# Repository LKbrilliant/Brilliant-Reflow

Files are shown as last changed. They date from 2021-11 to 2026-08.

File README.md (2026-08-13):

# Brilliant-Reflow
A complete DIY solution for converting a consumer oven into a temperature controlled reflow oven for PCB soldering.

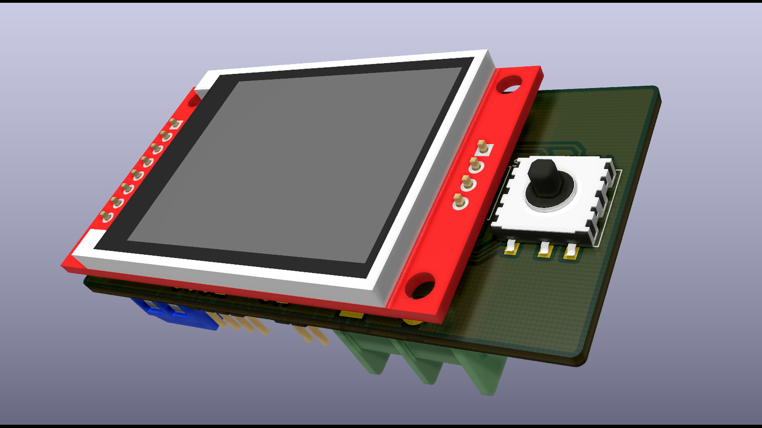
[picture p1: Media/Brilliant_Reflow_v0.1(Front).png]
PCB Front

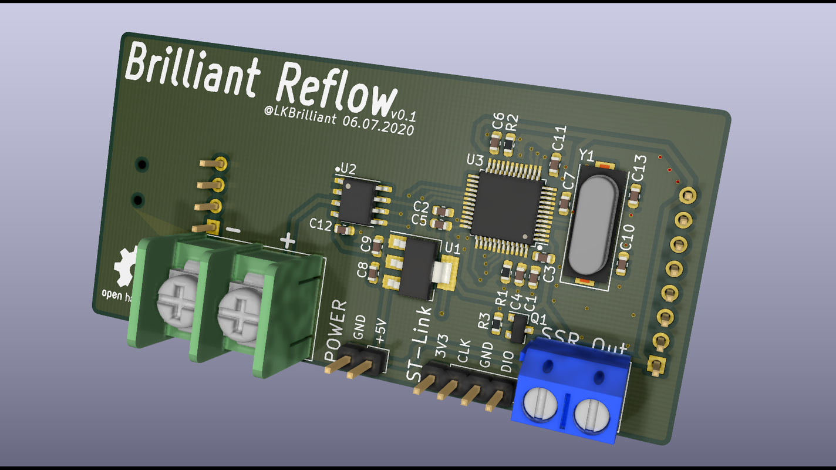
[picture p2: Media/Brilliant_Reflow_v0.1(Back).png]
PCB Back

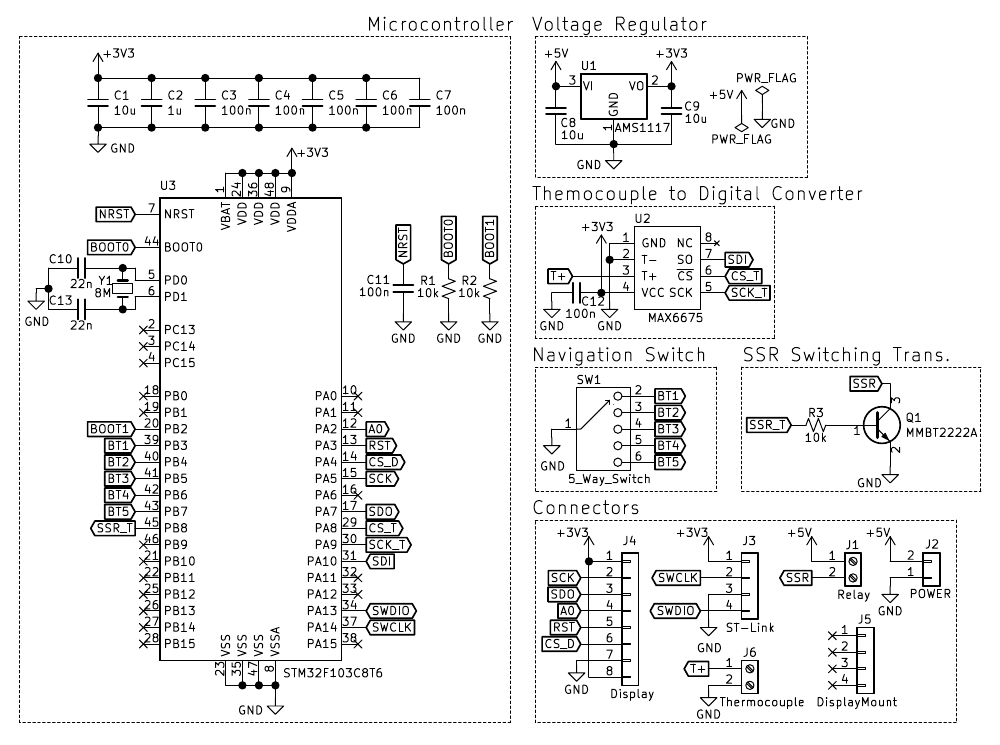
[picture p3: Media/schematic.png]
Schematic

Oven
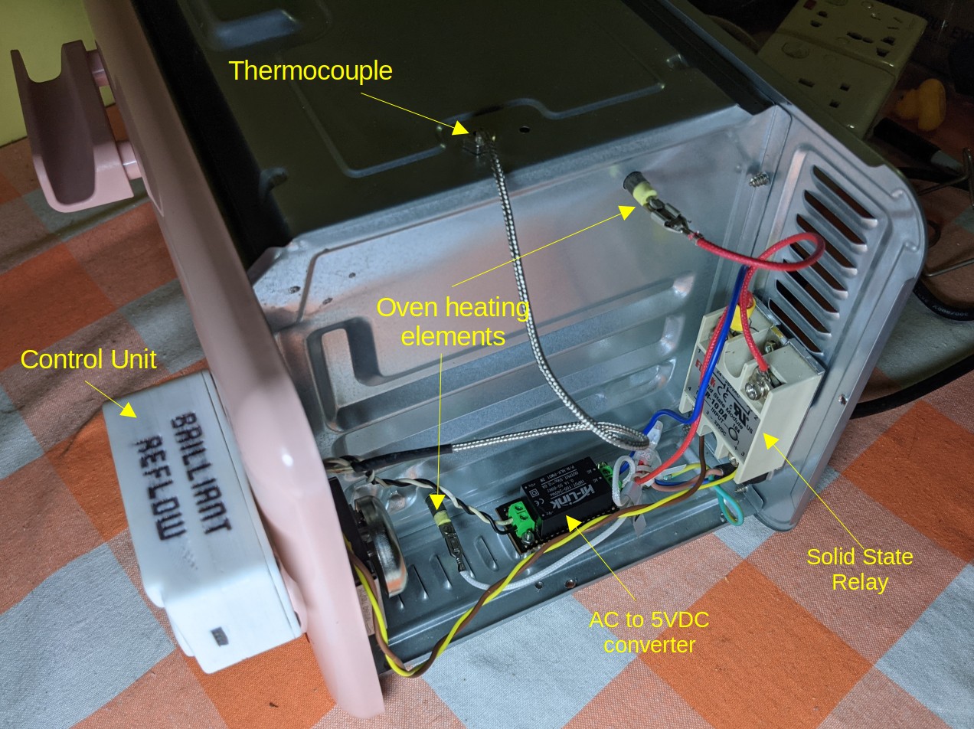
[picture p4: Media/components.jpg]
Components


https://github.com/user-attachments/assets/c0d352e0-495b-4052-a3d3-c1c6e0b2d40d

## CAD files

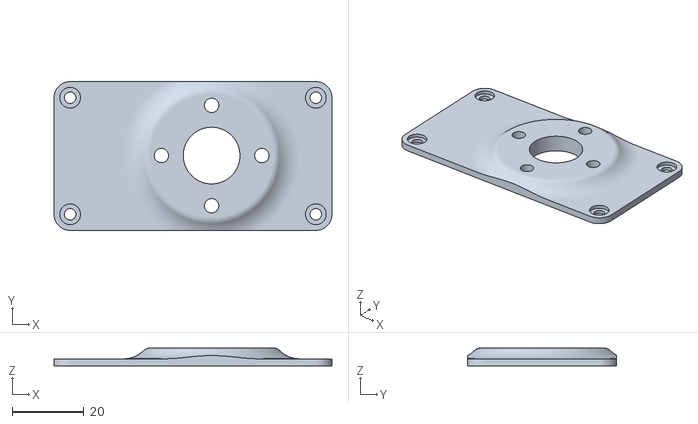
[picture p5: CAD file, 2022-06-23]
CAD/Case Back.stl
77.5 x 41.5 x 5.00

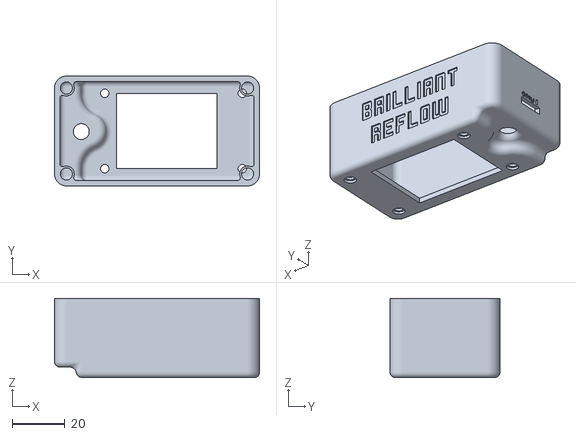
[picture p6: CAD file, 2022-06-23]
CAD/Case Front.stl
77.5 x 41.5 x 30.0

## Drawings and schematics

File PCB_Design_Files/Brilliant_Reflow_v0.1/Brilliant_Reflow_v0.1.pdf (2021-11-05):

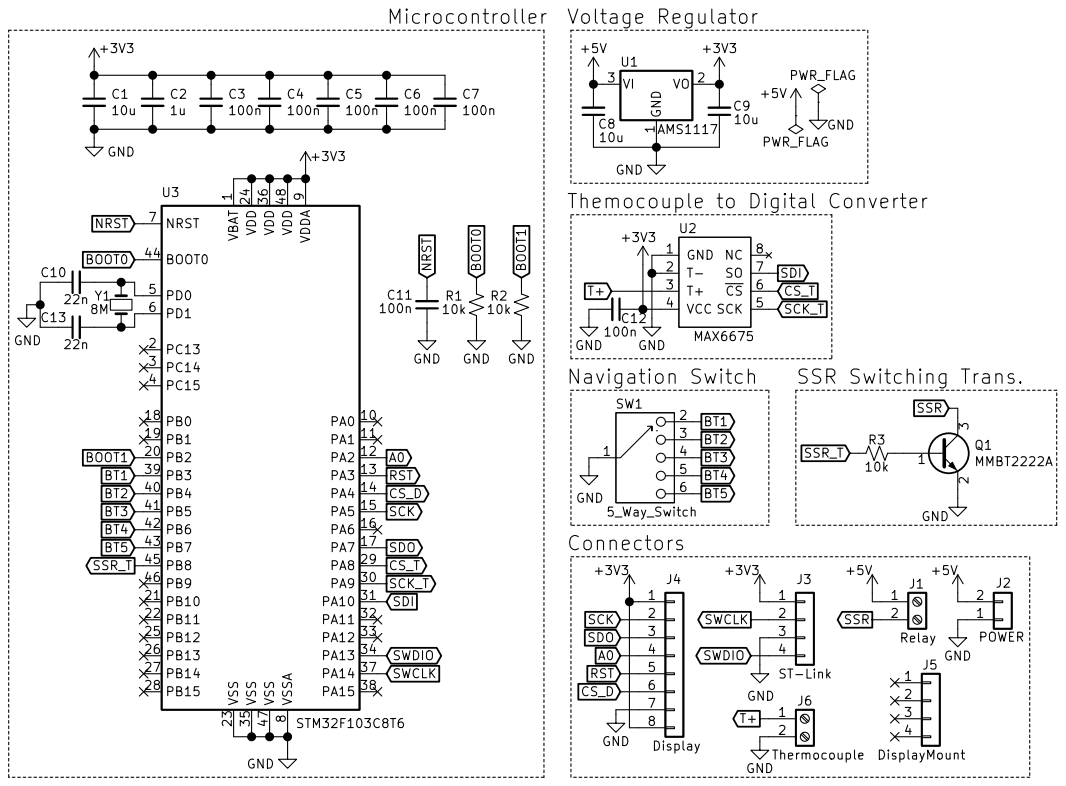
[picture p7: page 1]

File: Brilliant_Reflow_v0.1.sch Sheet: / github.com/lkbrilliant

Id: 1/1 Title: Brilliant Reflow

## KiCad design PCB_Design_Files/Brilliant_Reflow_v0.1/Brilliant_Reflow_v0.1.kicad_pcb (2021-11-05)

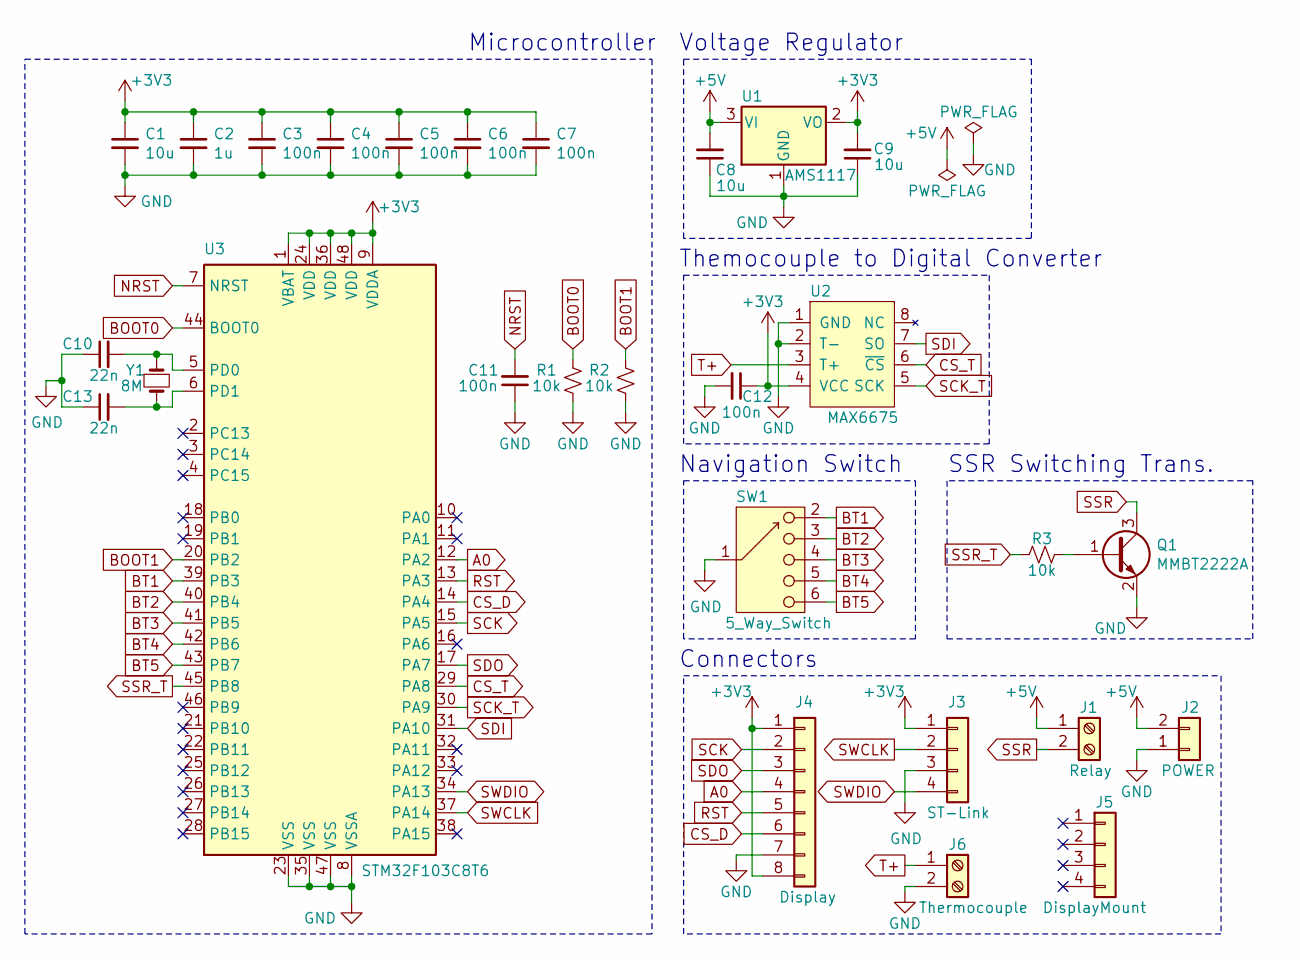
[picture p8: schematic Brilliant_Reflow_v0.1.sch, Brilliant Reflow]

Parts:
C1, C8, C9: 10u; C_0603_1608Metric
C2: 1u; C_0603_1608Metric
C3, C4, C5, C6, C7, C11, C12: 100n; C_0603_1608Metric
C10, C13: 22n; C_0603_1608Metric
J1: Relay; TerminalBlock_bornier-2_P5.08mm
J2: POWER; PinHeader_1x02_P2.54mm_Vertical
J3: ST-Link; PinHeader_1x04_P2.54mm_Vertical
J4: Display; PinSocket_1x08_P2.54mm_Vertical
J5: DisplayMount; PinSocket_1x04_P2.54mm_Vertical
J6: Thermocouple; TerminalBlock_7.62mm_2p
Q1: MMBT2222A; SOT-23
R1, R2, R3: 10k; R_0603_1608Metric
SW1: 5_Way_Switch
U1: AMS1117; SOT-223-3_TabPin2
U2: MAX6675; SO-8_3.9x4.9mm_P1.27mm
U3: STM32F103C8T6; LQFP-48_7x7mm_P0.5mm
Y1: 8M; Crystal_SMD_HC49-SD

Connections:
+3V3: C1.1, C2.1, C3.1, C4.1, C5.1, C6.1, C7.1, C9.2, C12.1, J3.1, J4.1, J4.8, U1.2 (VO), U2.4 (VCC), U3.1 (VBAT), U3.9 (VDDA), U3.24 (VDD), U3.36 (VDD), U3.48 (VDD)
+5V: C8.2, J1.1, J2.2, U1.3 (VI)
A0: J4.4, U3.12 (PA2)
BOOT0: R1.1, U3.44 (BOOT0)
BOOT1: R2.1, U3.20 (PB2)
BT1: SW1.2, U3.39 (PB3)
BT2: SW1.3, U3.40 (PB4)
BT3: SW1.4, U3.41 (PB5)
BT4: SW1.5, U3.42 (PB6)
BT5: SW1.6, U3.43 (PB7)
CS_D: J4.6, U3.14 (PA4)
CS_T: U2.6 (~CS), U3.29 (PA8)
GND: C1.2, C2.2, C3.2, C4.2, C5.2, C6.2, C7.2, C8.1, C9.1, C10.1, C11.1, C12.2, C13.1, J2.1, J3.3, J4.7, J6.2, Q1.2 (E), R1.2, R2.2, SW1.1, U1.1 (GND), U2.1 (GND), U2.2 (T-), U3.8 (VSSA), U3.23 (VSS), U3.35 (VSS), U3.47 (VSS)
NRST: C11.2, U3.7 (NRST)
unnamed: C10.2, U3.5 (PD0), Y1.1
unnamed: C13.2, U3.6 (PD1), Y1.2
unnamed: Q1.1 (B), R3.1
RST: J4.5, U3.13 (PA3)
SCK: J4.2, U3.15 (PA5)
SCK_T: U2.5 (SCK), U3.30 (PA9)
SDI: U2.7 (SO), U3.31 (PA10)
SDO: J4.3, U3.17 (PA7)
SSR: J1.2, Q1.3 (C)
SSR_T: R3.2, U3.45 (PB8)
SWCLK: J3.2, U3.37 (PA14)
SWDIO: J3.4, U3.34 (PA13)
T+: J6.1, U2.3 (T+)

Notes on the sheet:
Microcontroller
Themocouple to Digital Converter
Voltage Regulator
Navigation Switch
Connectors
SSR Switching Trans.

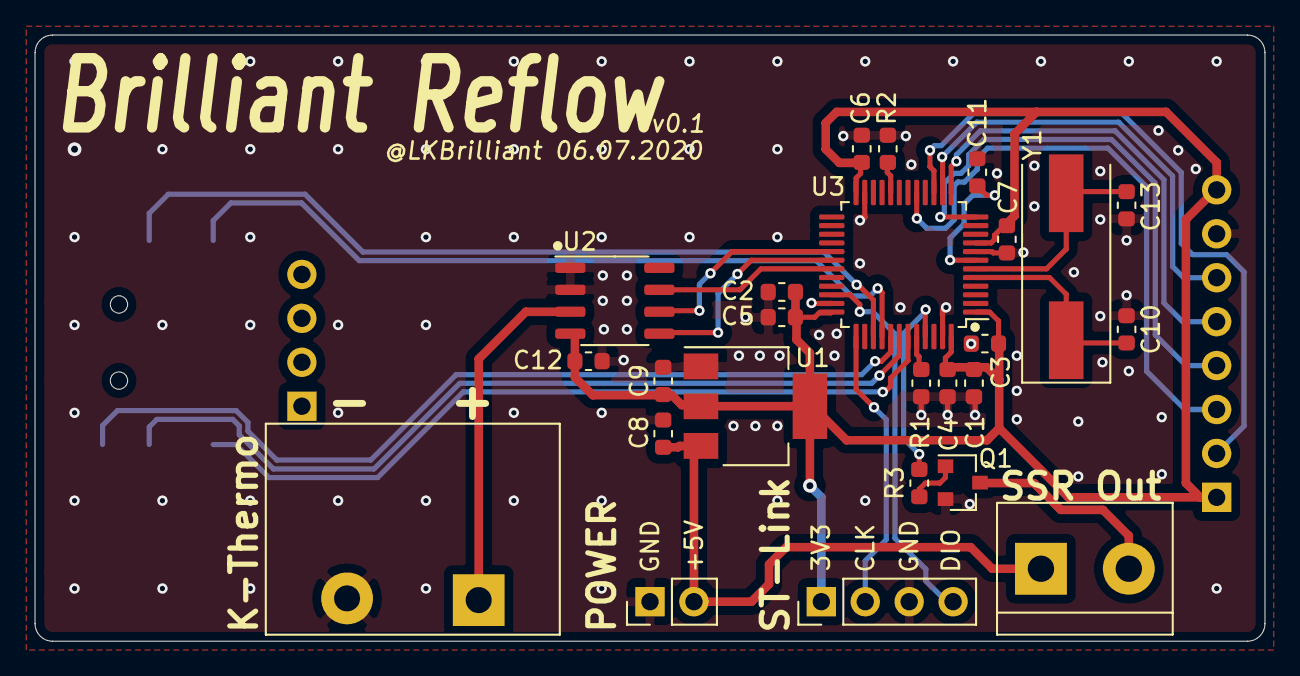
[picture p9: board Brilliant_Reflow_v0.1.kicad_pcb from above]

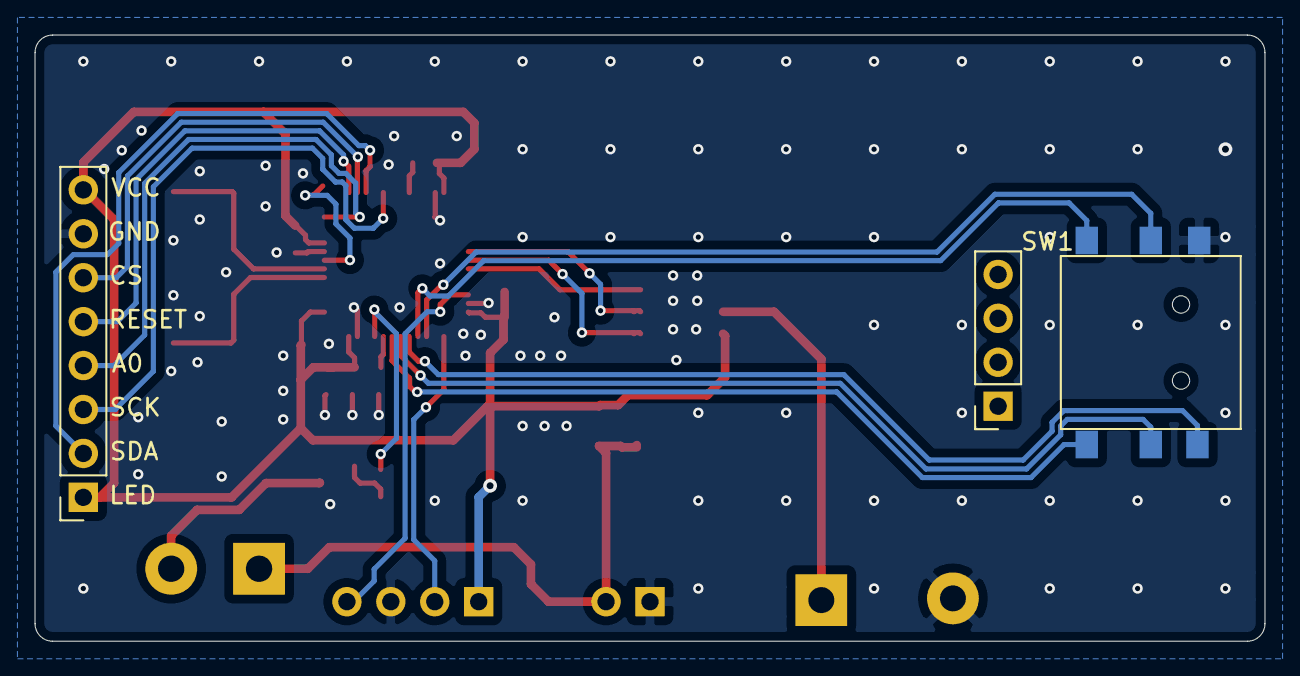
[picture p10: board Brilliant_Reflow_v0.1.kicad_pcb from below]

Board: 2 copper layers, 71.1 x 35.1 mm, 28 parts (3 on the bottom side), 27 nets.

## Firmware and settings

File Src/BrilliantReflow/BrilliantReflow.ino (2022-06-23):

/* 
* ░█▀▄░█▀▄░▀█▀░█░░░█░░░▀█▀░█▀█░█▀█░▀█▀░░░█▀▄░█▀▀░█▀▀░█░░░█▀█░█░█
* ░█▀▄░█▀▄░░█░░█░░░█░░░░█░░█▀█░█░█░░█░░░░█▀▄░█▀▀░█▀▀░█░░░█░█░█▄█
* ░▀▀░░▀░▀░▀▀▀░▀▀▀░▀▀▀░▀▀▀░▀░▀░▀░▀░░▀░░░░▀░▀░▀▀▀░▀░░░▀▀▀░▀▀▀░▀░▀
* Project:    Brilliant Reflow
* Code by:    Anuradha Gunawardhana
* version:    v1.0.0
* Date:       2022.01.30
* 
* Hardware:   Display - ST7735(128x160)TFT
*             Thermocouple Interface - MAX6675
*             Microcontroller - STM32F103C8T6
*             ST-LINK - CubeProgrammer - https://www.st.com/en/development-tools/stm32cubeprog.html
* 
* Libraries:  PID(v1.2.0) by Brett Beauregard : https://github.com/br3ttb/Arduino-PID-Library
*             Ucglib(v1.5.2) by Oliver: https://github.com/olikraus/ucglib
*             MAX6675(v1.1.0) by Adafruit: https://github.com/adafruit/MAX6675-library
* 
* Arduino STM32 Boards:(v2.0.0) https://github.com/stm32duino/Arduino_Core_STM32
* 
* Note: If Ucglib did not compile with the STM32(arm architecture) add the following lines just 
*       after "Ucglib.h" line at the begining of the 'Ucglib.cpp'. 
*       
*                 #if defined(__NOP)
*                 #undef __NOP
*                 #endif
*                 #define __NOP __asm volatile ("nop")
*                 #endif
*       
*       You can find the Ucglib.cpp' on; Windows: Documents/Arduino/libraries/Ucglib/src/Ucglib.cpp
*                                        Linux: /home/USERNAME/Arduino/libraries/Ucglib/src/Ucglib.cpp
* 
* License: MIT License
* 
* Copyright (c) 2021 Anuradha Gunawardhana
* 
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
* THE SOFTWARE IS PROVIDED "AS IS", WITHOUT WARRANTY OF ANY KIND, EXPRESS OR
* IMPLIED, INCLUDING BUT NOT LIMITED TO THE WARRANTIES OF MERCHANTABILITY,
* FITNESS FOR A PARTICULAR PURPOSE AND NONINFRINGEMENT. IN NO EVENT SHALL THE
* AUTHORS OR COPYRIGHT HOLDERS BE LIABLE FOR ANY CLAIM, DAMAGES OR OTHER
* LIABILITY, WHETHER IN AN ACTION OF CONTRACT, TORT OR OTHERWISE, ARISING FROM,
* OUT OF OR IN CONNECTION WITH THE SOFTWARE OR THE USE OR OTHER DEALINGS IN THE
* SOFTWARE.
*/

#include <SPI.h>
#include <PID_v1.h>
#include <EEPROM.h>
#include "Ucglib.h"
#include "max6675.h"

// Unique identifiers for colors
#define black   100
#define yellow  101
#define red     102
#define green   103
#define blackOnYellow 201
#define yellowOnBlack 202

#define SSR_out PB8

#define btnDebounceDelay  300
#define btnHoldDelay     1000
#define btnHoldUpdateRate  50
#define tempSampleRate    200

Ucglib_ST7735_18x128x160_HWSPI ucg(PA2, PA4, PA3);
MAX6675 thermocouple(PA9, PA8, PA10);

bool debug = false;        // Show PID output info on the disply when heating

bool blinkState = false;

bool editSettings = false;
bool resetRequest = false;
bool saveRequest = false;
bool save_pressed = false;
bool reset_pressed = false;

double default_K_pid[3] = {4, 0.01, 5};
double K_pid[3]={0,0,0};
String pid[3] = {"Kp:","Ki:","Kd:"};
String pid_[3] = {"P","I","D"};
bool pidInit = false;
double Setpoint, Input, Output;
PID myPID(&Input, &Output, &Setpoint, K_pid[0], K_pid[1], K_pid[2], DIRECT);

byte p4LastSelect_v = 1;
byte p4LastSelect_h = 1;

bool backRequest = false;
bool startStopRequest = false;
bool settingsPageRequest = false;
byte request_draw_profile_page = 0;

unsigned long lstTempRead = 0;
unsigned long lstBlink = 0;
float temp = 0;
byte tempPos[2] = {94, 52};

bool heating = false;
unsigned long lstPlotDraw = 0;
float plotTime = 0;
float plotDrawRate = 500;  // in milliseconds

int default_profiles[3][6][2] =  {{{25, 0}, {150, 100}, {180, 160}, {240, 200}, {240, 210}, {100, 300}},   // Profile 1
                                  {{25, 0}, {130, 80}, {150, 240}, {230, 300}, {230, 310}, {100, 400}},    // Profile 2
                                  {{25, 0}, {130, 60}, {150, 230}, {240, 290}, {240, 310}, {100, 380}}};   // Profile 3
int profiles[3][6][2];

int maxTemp = 0;
int minTemp = 0;
int maxTime = 0;

const byte main_btn_pos[3][2] = {{70, 20}, {40, 20}, {10, 20}};
const byte main_btn_text_pos[3][2] = {{77, 51}, {47, 51}, {17, 51}};
const String main_btn_labels[3] = {"PROFILE 1", "PROFILE 2", "PROFILE 3"};
const byte main_btn_height = 25;
const byte main_btn_width = 120;

byte h_btn_pos[3][2] = {{83, 5}, {83, 56}, {83, 107}};
byte h_btn_text_pos[3][2] = {{87, 17}, {87, 66}, {87, 120}};
String h_btn_labels[3] = {"BACK", "START", "EDIT"};
byte h_btn_height = 18;
byte h_btn_width = 47;

volatile byte vertical_pos = 1;
volatile byte horizontal_pos = 1;

byte page = 0;
byte previosPage = 0;

volatile unsigned long lstBtnBounce = 0;
volatile unsigned long hold_start = 0;
unsigned long last_val_change = 0;

void setup(void) {
  pinMode(PB3, INPUT_PULLUP);
  pinMode(PB4, INPUT_PULLUP);
  pinMode(PB5, INPUT_PULLUP);
  pinMode(PB6, INPUT_PULLUP);
  pinMode(PB7, INPUT_PULLUP);
  pinMode(PB8, OUTPUT);

  attachInterrupt(digitalPinToInterrupt(PB3), up, FALLING);
  attachInterrupt(digitalPinToInterrupt(PB4), center, RISING);
  attachInterrupt(digitalPinToInterrupt(PB5), right, FALLING);
  attachInterrupt(digitalPinToInterrupt(PB6), down, FALLING);
  attachInterrupt(digitalPinToInterrupt(PB7), left, FALLING);

  ucg.begin(UCG_FONT_MODE_SOLID);
  ucg.setFontPosBaseline();
  ucg.setPrintDir(1);
  draw_main_page();

  // initiate the emulated EEPROM
  if (!EEPROM_check()) EEPROM_set_default();
  EEPROM_get();

  // PID Controller
  Setpoint = 50;
  temp = thermocouple.readCelsius();
  Input = temp;
  myPID.SetOutputLimits(0, 255);
  myPID.SetTunings(K_pid[0], K_pid[1], K_pid[2]);
}

void loop(void) {
  if (backRequest) {
    backRequest = false;
    goBack();
  }
  if (startStopRequest) {
    startStopRequest = false;
    startStop();
  }
  if (request_draw_profile_page != 0) {
    request_draw_profile_page = 0;
    horizontal_pos = 1; // select the "BACK"
    draw_profile_page(vertical_pos);
  }
  if (settingsPageRequest){
    settingsPageRequest = false;
    draw_settings_page(1);
  }
  if (resetRequest){
    resetRequest = false;
    EEPROM_set_default();
    EEPROM_get();         // get the new save values from the EEPROM
    default_h_btn_para();
    page = previosPage;   // setting the correct page
    draw_settings_page(3);
  }
  if (saveRequest){
    saveRequest = false;
    EEPROM_save();
    EEPROM_get();
    default_h_btn_para();
    page = previosPage;   // setting the correct page
    draw_settings_page(2);
  }
  if (heating) { // Plot the temperature on the graph
    if (!pidInit) {
      pidInit = true;
      myPID.SetMode(AUTOMATIC);
    }
    // Show the real time value of the Temperature
    setColor(yellowOnBlack);
    ucg.setFont(ucg_font_6x12_mr);  // use 'mr' font to completely fill the background

    if ((millis() - lstTempRead) > tempSampleRate) { // Read the thermocouple in the set interval
      temp = thermocouple.readCelsius();
      lstTempRead = millis();
    }
    ucg.setPrintPos(tempPos[0], tempPos[1]);
    ucg.print(String(temp));
    if (temp < 100.0){
      setColor(black);
      ucg.drawBox(tempPos[0]+1,tempPos[1]+30,7,5); // to clear the last decimal when going from 100.00 to 99.75 
    }

    if ((millis() - lstPlotDraw) > plotDrawRate) {  // draw the plot in a set interval
      plotTime = plotTime + plotDrawRate / 1000;
      setColor(yellowOnBlack);
      ucg.setPrintPos(tempPos[0]-10, tempPos[1]);
      ucg.print(String(plotTime));
      float currentTemp = thermocouple.readCelsius();

      float T = ((60 * (currentTemp - minTemp)) / (maxTemp - minTemp)) + 10;  // height of plot is 60
      float t = ((120 * plotTime) / maxTime) + 20;                // width of plot is 120

      if (T > 70) T = 70;     // use constrain(x, a, b)
      if (T < 11) T = 11;
      if (t < 21) t = 21;
      setColor(red);
      ucg.drawPixel(T, t);     // Plot the temperature on the graph

      if(debug){
        ucg.setPrintPos(73,35);           
        ucg.print("out:"+String(Output));
        ucg.setPrintPos(63,35);           
        ucg.print("set:"+String(Setpoint));
        for (byte i=0; i<=2; i++){
          ucg.setFont(ucg_font_6x12_tr);
          ucg.setPrintPos(72 - i*10, 127);
          ucg.print(pid_[i]);
          ucg.setFont(ucg_font_6x12_mr);
          ucg.setPrintPos(72 - i*10, 134);
          ucg.print(K_pid[i]);
        }
      }

      if (plotTime > maxTime) {
        startStopRequest = true;
      }
      lstPlotDraw = millis();
    }
    blinking_dot(red);
    // PID Controller
    calculateSetPoint();  // calculate the setpoint based on the plot
    Input = temp;         // if the temperature function directly provided, the displaying of the temp will stop 
    myPID.Compute();
    analogWrite(SSR_out, Output);
  }
  if(!digitalRead(PB3) && (millis()-hold_start)>=btnHoldDelay) holding_up();
  if(!digitalRead(PB6) && (millis()-hold_start)>=btnHoldDelay) holding_down();
}

void up() {
  if ((millis() - lstBtnBounce) > btnDebounceDelay) {
    hold_start = millis();
    if (!editSettings){
      vertical_pos -= 1;
      if (page == 0 && vertical_pos == 0) vertical_pos = 3;
      else if (page == 4 && horizontal_pos == 1 && vertical_pos == 0) vertical_pos = 7;
      else if (page == 4 && horizontal_pos == 2 && vertical_pos == 0) vertical_pos = 7;
      else if (page == 4 && horizontal_pos == 3 && vertical_pos == 0) vertical_pos = 4;
    }
    else{
      if (horizontal_pos == 1 && profiles[previosPage-1][vertical_pos-2][1] < 500) profiles[previosPage-1][vertical_pos-2][1] += 1; // Max Time limit
      else if (horizontal_pos == 2 && profiles[previosPage-1][vertical_pos-2][0] < 250) profiles[previosPage-1][vertical_pos-2][0] += 1; // Max Temp limit
      else if (horizontal_pos == 3 && K_pid[vertical_pos-2] < 9.99) K_pid[vertical_pos-2] += 0.01;
    }
    drawSelector();
    lstBtnBounce = millis();
  }
}

void down() {
  if ((millis() - lstBtnBounce) > btnDebounceDelay) {
    hold_start = millis();
    if (!editSettings){
      vertical_pos += 1;
      if (page == 0 && vertical_pos == 4) vertical_pos = 1;
      else if (page == 4 && horizontal_pos == 1 && vertical_pos == 8) vertical_pos = 1;
      else if (page == 4 && horizontal_pos == 2 && vertical_pos == 8) vertical_pos = 1;
      else if (page == 4 && horizontal_pos == 3 && vertical_pos == 5) vertical_pos = 1;
    }
    else{
      if (horizontal_pos == 1 && profiles[previosPage-1][vertical_pos-2][1] > 0) profiles[previosPage-1][vertical_pos-2][1] -= 1;  // Min Time limit
      else if (horizontal_pos == 2 && profiles[previosPage-1][vertical_pos-2][0] > 25) profiles[previosPage-1][vertical_pos-2][0] -= 1; // Min Temp limit
      else if (horizontal_pos == 3 && K_pid[vertical_pos-2] > 0) K_pid[vertical_pos-2] -= 0.01;
    }
    drawSelector();
    lstBtnBounce = millis();
  }
}

void left() {
  if ((millis() - lstBtnBounce) > btnDebounceDelay) {
    if (!heating && !editSettings){
      horizontal_pos -= 1;
      if (!save_pressed && !reset_pressed && horizontal_pos == 0) horizontal_pos = 3;
      if (page == 4){
        if ((save_pressed || reset_pressed) && (horizontal_pos == 1)) horizontal_pos = 3;
        else if (horizontal_pos == 3 && vertical_pos > 4) vertical_pos = 4; // jump to the shorter PID list
      }
      drawSelector();
      lstBtnBounce = millis();
    }
  }
}

void right() {
  if ((millis() - lstBtnBounce) > btnDebounceDelay) {
    if (!heating && !editSettings){
      horizontal_pos += 1;
      if (!save_pressed && !reset_pressed && horizontal_pos == 4) horizontal_pos = 1;
      if (page == 4){
        if ((save_pressed || reset_pressed) && (horizontal_pos == 4)) horizontal_pos = 2;
        else if (horizontal_pos == 3 && vertical_pos > 4) vertical_pos = 4; // jump to the shorter PID list
      } 
      drawSelector();
      lstBtnBounce = millis();
    }
  }
}

void holding_up(){
  if (editSettings && (millis() - last_val_change) > btnHoldUpdateRate){
    if (horizontal_pos == 1 && profiles[previosPage-1][vertical_pos-2][1] < 500) profiles[previosPage-1][vertical_pos-2][1] += 1; // Max Time limit
    else if (horizontal_pos == 2 && profiles[previosPage-1][vertical_pos-2][0] < 250) profiles[previosPage-1][vertical_pos-2][0] += 1; // Max Temp limit
    else if (horizontal_pos == 3 && K_pid[vertical_pos-2] < 9.99) K_pid[vertical_pos-2] += 0.01;
    drawSelector();
    last_val_change = millis();
  }
}

void holding_down(){
  if (editSettings && (millis() - last_val_change) > btnHoldUpdateRate){
    if (horizontal_pos == 1 && profiles[previosPage-1][vertical_pos-2][1] > 0) profiles[previosPage-1][vertical_pos-2][1] -= 1;  // Min Time limit
    else if (horizontal_pos == 2 && profiles[previosPage-1][vertical_pos-2][0] > 25) profiles[previosPage-1][vertical_pos-2][0] -= 1; // Min Temp limit
    else if (horizontal_pos == 3 && K_pid[vertical_pos-2] > 0) K_pid[vertical_pos-2] -= 0.01;
    drawSelector();
    last_val_change = millis();
  }
}

void center() {
  if ((millis() - lstBtnBounce) > btnDebounceDelay) {
    if (page == 0) {
      request_draw_profile_page = vertical_pos;
    }
    else if (page == 1 || page == 2 || page == 3) {
      if (horizontal_pos == 1) backRequest = true;
      else if (horizontal_pos == 2) startStopRequest = true;
      else if (heating == false && horizontal_pos == 3) settingsPageRequest = true;
      else if (heating == true && horizontal_pos == 3) startStopRequest = true;
    }
    else if (page == 4) {
      if (vertical_pos == 1 && horizontal_pos == 1) backRequest = true;
      else if (vertical_pos == 1 && horizontal_pos == 2){
        if (!save_pressed && !reset_pressed){
          save_pressed = true;
          draw_yes_no_buttons("save");
        }
        else if (save_pressed){
          saveRequest = true;
          save_pressed = false;
          reset_pressed = false;
        }
        else if (reset_pressed){
          resetRequest = true;
          save_pressed = false;
          reset_pressed = false;
        }
      }
      else if (vertical_pos == 1 && horizontal_pos == 3){
        if (!reset_pressed && !save_pressed){
          reset_pressed = true; 
          draw_yes_no_buttons("reset");
        }
        else if (save_pressed || reset_pressed){
          default_h_btn_para();
          page = previosPage;   // setting the correct page
          if (save_pressed) draw_settings_page(2);
          else if (reset_pressed) draw_settings_page(3);
          save_pressed = false;
          reset_pressed = false;
        }
      }
      else {
        editSettings = !editSettings;
        drawSelector();
      }
    }
    lstBtnBounce = millis();
  }
}

void drawBorder() {
  // Frame
  ucg.drawVLine(0, 0, 144);
  ucg.drawLine(0, 144, 15, 159);
  ucg.drawHLine(15, 159, 113);
  ucg.drawVLine(127, 132, 27);
  ucg.drawLine(127, 132, 105, 110);
  ucg.drawVLine(105, 0, 110);
  ucg.drawHLine(0, 0, 105);
  // Title
  ucg.drawBox(108, 0, 127, 109);
  ucg.drawTriangle(108, 109, 128, 109, 127, 129);
}

void drawBtn(byte x, byte y, byte h, byte w, byte font_x, byte font_y, String label) { // x,y - (bottom left), h - height
  ucg.setColor(0, 250, 245, 0);   // Bright Yellow
  ucg.drawBox(x, y, h, w);
  ucg.setColor(0, 0, 0, 0);
  ucg.drawTriangle(x + (h / 2) + 1, y, x + h, y, x + h, y + (h / 2));   // top left triangle
  ucg.drawTriangle(x, (y + w) - (h / 2), x, y + w, x + (h / 2), y + w); // bottom right triangle
  ucg.setColor(1, 250, 245, 0); // background Yellow
  ucg.setPrintPos(font_x, font_y);
  ucg.print(label);
}

void title(String label) {
  ucg.setFont(ucg_font_7x14_tr);  // Final
  ucg.setPrintPos(112, 2);
  ucg.print(label);
}

void draw_main_buttons() {
  ucg.setFont(ucg_font_7x14_tr);
  for (byte i = 0; i <= 2; i++) {
    drawBtn(main_btn_pos[i][0], main_btn_pos[i][1], main_btn_height, main_btn_width, main_btn_text_pos[i][0], main_btn_text_pos[i][1], main_btn_labels[i]);
  }
}

void draw_horizontal_buttons() {
  setColor(black);
  ucg.drawBox(81,2,23,100); // clear the temp and time info after heating
  ucg.setFont(ucg_font_6x13_tr);
  for (byte i = 0; i < 3; i++) {
    drawBtn(h_btn_pos[i][0], h_btn_pos[i][1], h_btn_height, h_btn_width, h_btn_text_pos[i][0], h_btn_text_pos[i][1], h_btn_labels[i]);
  }
}

void drawSelector() {
  if (page == 0) selector_main_buttons(vertical_pos);
  else if (page == 1 || page == 2 || page == 3) selector_horizontal_buttons(horizontal_pos);
  else if (page == 4){
    if (save_pressed || reset_pressed) selector_horizontal_buttons(horizontal_pos);
    else selector_settings_page(vertical_pos,horizontal_pos);
  }
}

void selector_main_buttons(byte v) {
  for (byte u = 1; u <= 3; u++) {
    if (v != u) {
      ucg.setColor(0, 0, 0, 0);
      ucg.drawLine((main_btn_pos[u - 1][0] + main_btn_height / 2) + 3, main_btn_pos[u - 1][1], main_btn_pos[u - 1][0] +  main_btn_height, (main_btn_pos[u - 1][1] +  main_btn_height / 2) - 2);
      ucg.drawLine((main_btn_pos[u - 1][0] + main_btn_height / 2) + 4, main_btn_pos[u - 1][1], main_btn_pos[u - 1][0] +  main_btn_height, (main_btn_pos[u - 1][1] +  main_btn_height / 2) - 3);
      ucg.drawLine(main_btn_pos[u - 1][0], (main_btn_pos[u - 1][1] + main_btn_width - main_btn_height / 2) + 3, (main_btn_pos[u - 1][0] + main_btn_height / 2) - 3, main_btn_pos[u - 1][1] + main_btn_width);
      ucg.drawLine(main_btn_pos[u - 1][0], (main_btn_pos[u - 1][1] + main_btn_width - main_btn_height / 2) + 4, (main_btn_pos[u - 1][0] + main_btn_height / 2) - 4, main_btn_pos[u - 1][1] + main_btn_width);
    }
  }
  ucg.setColor(0, 250, 245, 0); // Bright Yellow
  ucg.drawLine((main_btn_pos[v - 1][0] + main_btn_height / 2) + 3, main_btn_pos[v - 1][1], main_btn_pos[v - 1][0] +  main_btn_height, (main_btn_pos[v - 1][1] +  main_btn_height / 2) - 2);
  ucg.drawLine((main_btn_pos[v - 1][0] + main_btn_height / 2) + 4, main_btn_pos[v - 1][1], main_btn_pos[v - 1][0] +  main_btn_height, (main_btn_pos[v - 1][1] +  main_btn_height / 2) - 3);

  ucg.drawLine(main_btn_pos[v - 1][0], (main_btn_pos[v - 1][1] + main_btn_width - main_btn_height / 2) + 3, (main_btn_pos[v - 1][0] + main_btn_height / 2) - 3, main_btn_pos[v - 1][1] + main_btn_width);
  ucg.drawLine(main_btn_pos[v - 1][0], (main_btn_pos[v - 1][1] + main_btn_width - main_btn_height / 2) + 4, (main_btn_pos[v - 1][0] + main_btn_height / 2) - 4, main_btn_pos[v - 1][1] + main_btn_width);
}

void selector_horizontal_buttons(byte h) {
  byte u;
  if (save_pressed || reset_pressed) u = 1;
  else u = 0;
  for (u; u < 3; u++) {
    if (h != u+1) {
      ucg.setColor(0, 0, 0, 0);
      ucg.drawLine((h_btn_pos[u][0] + h_btn_height / 2) + 3, h_btn_pos[u][1], h_btn_pos[u][0] +  h_btn_height, (h_btn_pos[u][1] +  h_btn_height / 2) - 3);
      ucg.drawLine((h_btn_pos[u][0] + h_btn_height / 2) + 4, h_btn_pos[u][1], h_btn_pos[u][0] +  h_btn_height, (h_btn_pos[u][1] +  h_btn_height / 2) - 4);
      ucg.drawLine(h_btn_pos[u][0], (h_btn_pos[u][1] + h_btn_width - h_btn_height / 2) + 3, (h_btn_pos[u][0] + h_btn_height / 2) - 3, h_btn_pos[u][1] + h_btn_width);
      ucg.drawLine(h_btn_pos[u][0], (h_btn_pos[u][1] + h_btn_width - h_btn_height / 2) + 4, (h_btn_pos[u][0] + h_btn_height / 2) - 4, h_btn_pos[u][1] + h_btn_width);
    }
  }
  ucg.setColor(0, 250, 245, 0); // Bright Yellow
  ucg.drawLine((h_btn_pos[h - 1][0] + h_btn_height / 2) + 3, h_btn_pos[h - 1][1], h_btn_pos[h - 1][0] +  h_btn_height, (h_btn_pos[h - 1][1] +  h_btn_height / 2) - 3);
  ucg.drawLine((h_btn_pos[h - 1][0] + h_btn_height / 2) + 4, h_btn_pos[h - 1][1], h_btn_pos[h - 1][0] +  h_btn_height, (h_btn_pos[h - 1][1] +  h_btn_height / 2) - 4);

  ucg.drawLine(h_btn_pos[h - 1][0], (h_btn_pos[h - 1][1] + h_btn_width - h_btn_height / 2) + 3, (h_btn_pos[h - 1][0] + h_btn_height / 2) - 3, h_btn_pos[h - 1][1] + h_btn_width);
  ucg.drawLine(h_btn_pos[h - 1][0], (h_btn_pos[h - 1][1] + h_btn_width - h_btn_height / 2) + 4, (h_btn_pos[h - 1][0] + h_btn_height / 2) - 4, h_btn_pos[h - 1][1] + h_btn_width);
}
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

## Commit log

2021-11-05 Add KiCAD gitignore
2021-11-05 Add PCB Design and Fabrication files
    [Brilliant_Reflow_v0.1.kicad_pcb, Brilliant_Reflow_v0.1.sch]
2022-01-30 Add PID debug info toggle
2022-06-23 Upload CAD files
    [Case Back.stl, Case Front.stl]
